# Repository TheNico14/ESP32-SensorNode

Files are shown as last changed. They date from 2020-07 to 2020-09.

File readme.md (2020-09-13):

# ESP32 SensorNode

ESP32 SensorNode is an ESP32 based multi-purpose sensor for use in home automation systems.
It connects via Wi-Fi to your home automation system and allows you to receive the measured parameters such as temperature, humidity, brightness, and movement.

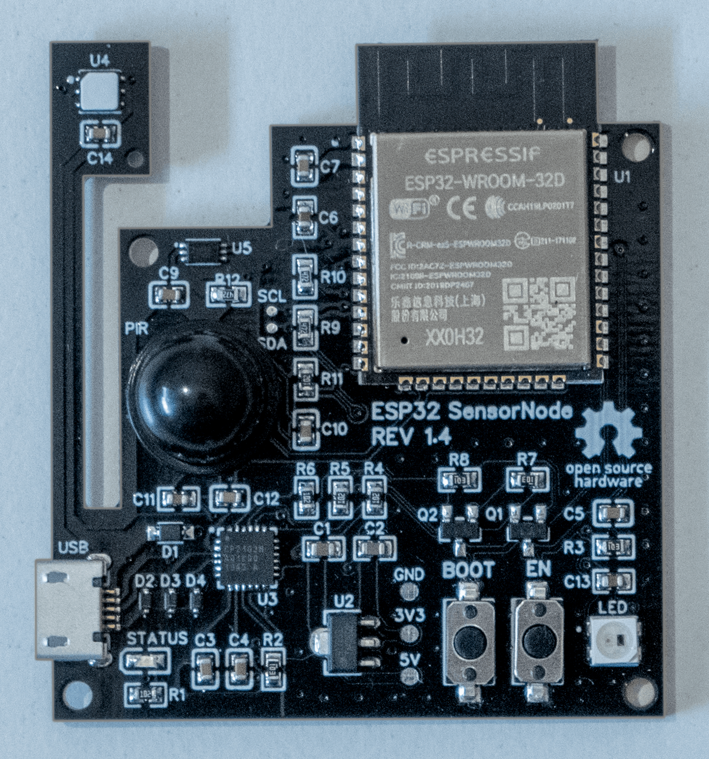
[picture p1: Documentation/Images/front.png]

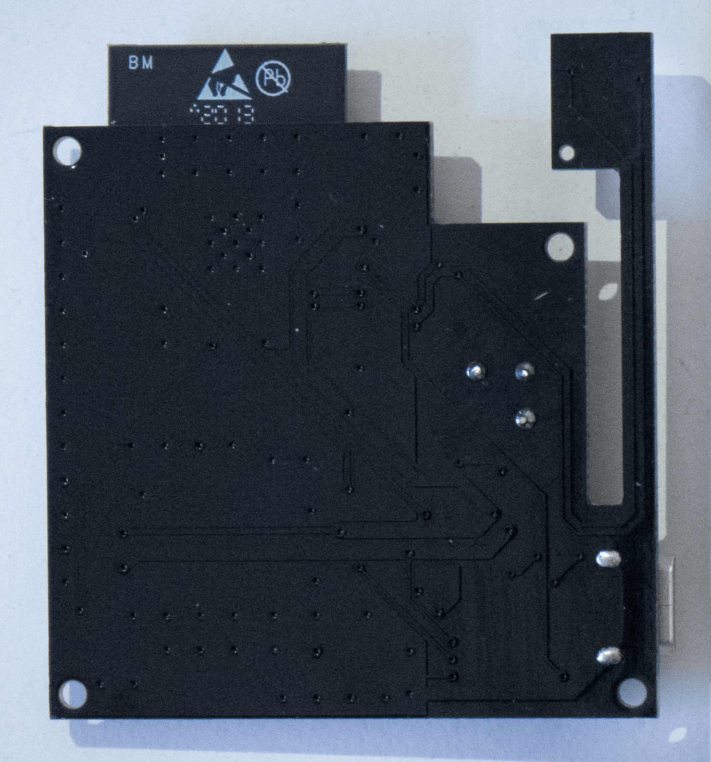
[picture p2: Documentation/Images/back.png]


The board can be programmed over USB and it's compatible with both [ESPHome](https://esphome.io/) (please read [below](https://github.com/TheNico14/ESP32-SensorNode#temperature-accuracy)) and the custom [ESP-IDF](https://github.com/espressif/esp-idf) software for use with [Home Assistant](https://www.home-assistant.io/). The custom ESP-IDF software utilizes [MQTT](https://en.wikipedia.org/wiki/MQTT) and it  should be compatible with other home automation systems.

The board dimensions are 5.08 x 4.57 cm (2 x 1.8 inches).

## Sensors

* Temperature / Humidity: SI7021\
    ± 0.4 °C (max), –10 to 85 °C\
    ± 3% RH (max), 0 – 80% RH
* Ambient Light: BH1750\
    1 - 65535 lx
* Motion sensor: AS312

## Features

* Programmable via USB
* Green status LED and digital RGB LED (WS2812B)
* Boot and Reset buttons

## Temperature accuracy

Due to the high consumption of the ESP32 with Wi-Fi enabled, the board tends to heat up over time and the measured temperature can increase by about 1°C.

The sensor has been isolated as much as possible from the rest of the system but it would be preferable to implement software that can limit consumption in order to obtain precise measurements.

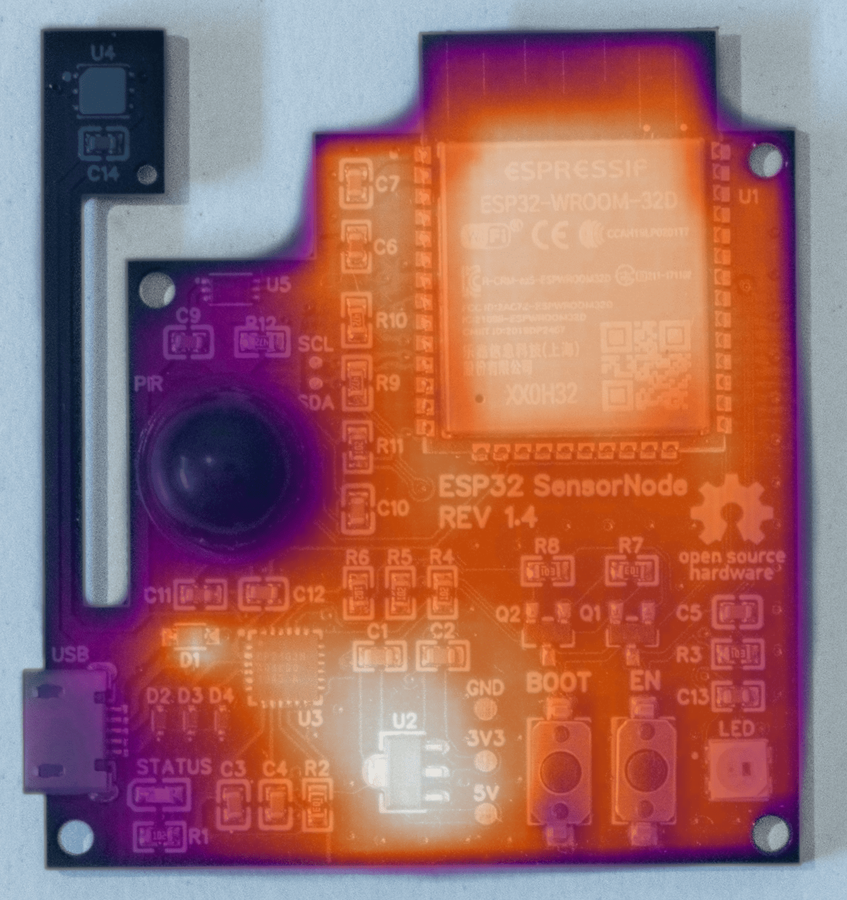
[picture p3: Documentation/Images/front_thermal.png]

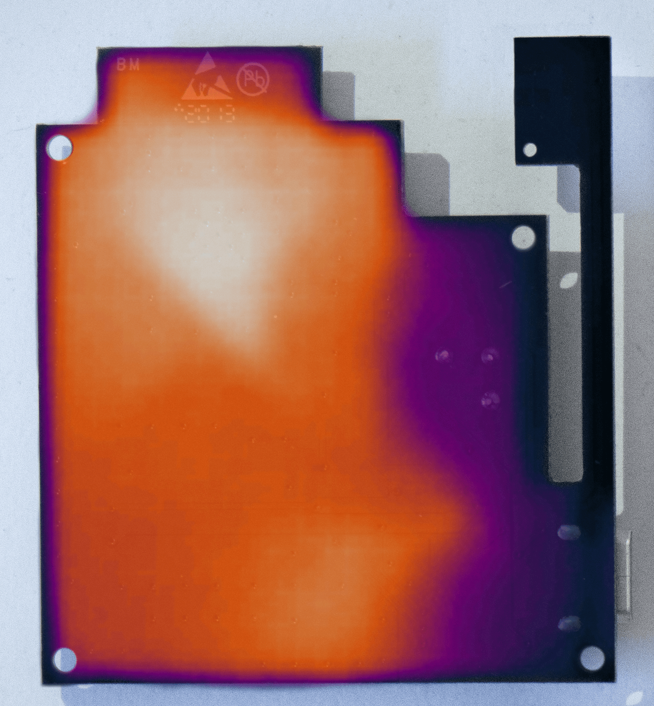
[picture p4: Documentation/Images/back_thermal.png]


At the time of writing, ESPHome allows you to configure wifi power saving but does not yet support light sleep, which would further reduce consumption and consequently unnecessary heat. It should be possible to use deep sleep with ESPHome but it has not been extensively tested.

An alternative custom software based on ESP-IDF has been developed for this board to minimize the problems caused by the high power consumption of the ESP32 microcontroller and its influence on measurements.
This software uses deep sleep and parsimonious use of Wi-Fi to minimize power consumption and the resulting increase of the board's temperature.

## Installation

The software installation guide can be found in the [project wiki](https://github.com/TheNico14/ESP32-SensorNode/wiki).

## Purchase an assembled unit

Since the production of this board requires relatively advanced soldering techniques and tools, upon request of some interested people, I opened a shop in Tindie where I sell already assembled boards.

[Purchase an ESP32 SensorNode on Tindie](https://www.tindie.com/products/thenico/esp32-sensornode/).

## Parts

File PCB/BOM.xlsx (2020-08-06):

Item | Label | Manufacturer Part | Value | Qty
1 | C1,C2,C6 | CL10A226MQ8NRNC | 22uF | 3
2 | C11,C13 | CL10A475KQ8NNND | 4.7uF | 2
3 | C3,C4,C5,C7,C9,C10,C12,C14 | 0603B104K500CT | 100nF | 8
4 | D1 | BAT760-7 |  | 1
5 | D2,D3,D4 | LESD5D5.0CT1G |  | 3
6 | EN,BOOT | K2-1107SP-A3SW-01 |  | 2
7 | LED | WS2812B-3535 |  | 1
8 | PIR | AS312 |  | 1
9 | Q1,Q2 | SS8050-G |  | 2
10 | R1,R4,R5,R6,R11 | 0603WAJ0102T5E | 1K | 5
11 | R2,R3,R7,R8 | 0603WAF1002T5E | 10K | 4
12 | R9,R10,R12 | WR06X472 JTL | 4.7K | 3
13 | STATUS | ORH-G36G |  | 1
14 | U1 | ESP32-WROOM-32D |  | 1
15 | U2 | HT7833 |  | 1
16 | U3 | CP2102N-A01-GQFN24 |  | 1
17 | U4 | SI7021 |  | 1
19 | U5 | BH1750FVI-TR |  | 1
20 | USB | U-F-M5WD-W-1 |  | 1
21 |  | PIR COVER |  | 1

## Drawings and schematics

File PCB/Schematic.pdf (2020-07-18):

## USB

## Power Supply

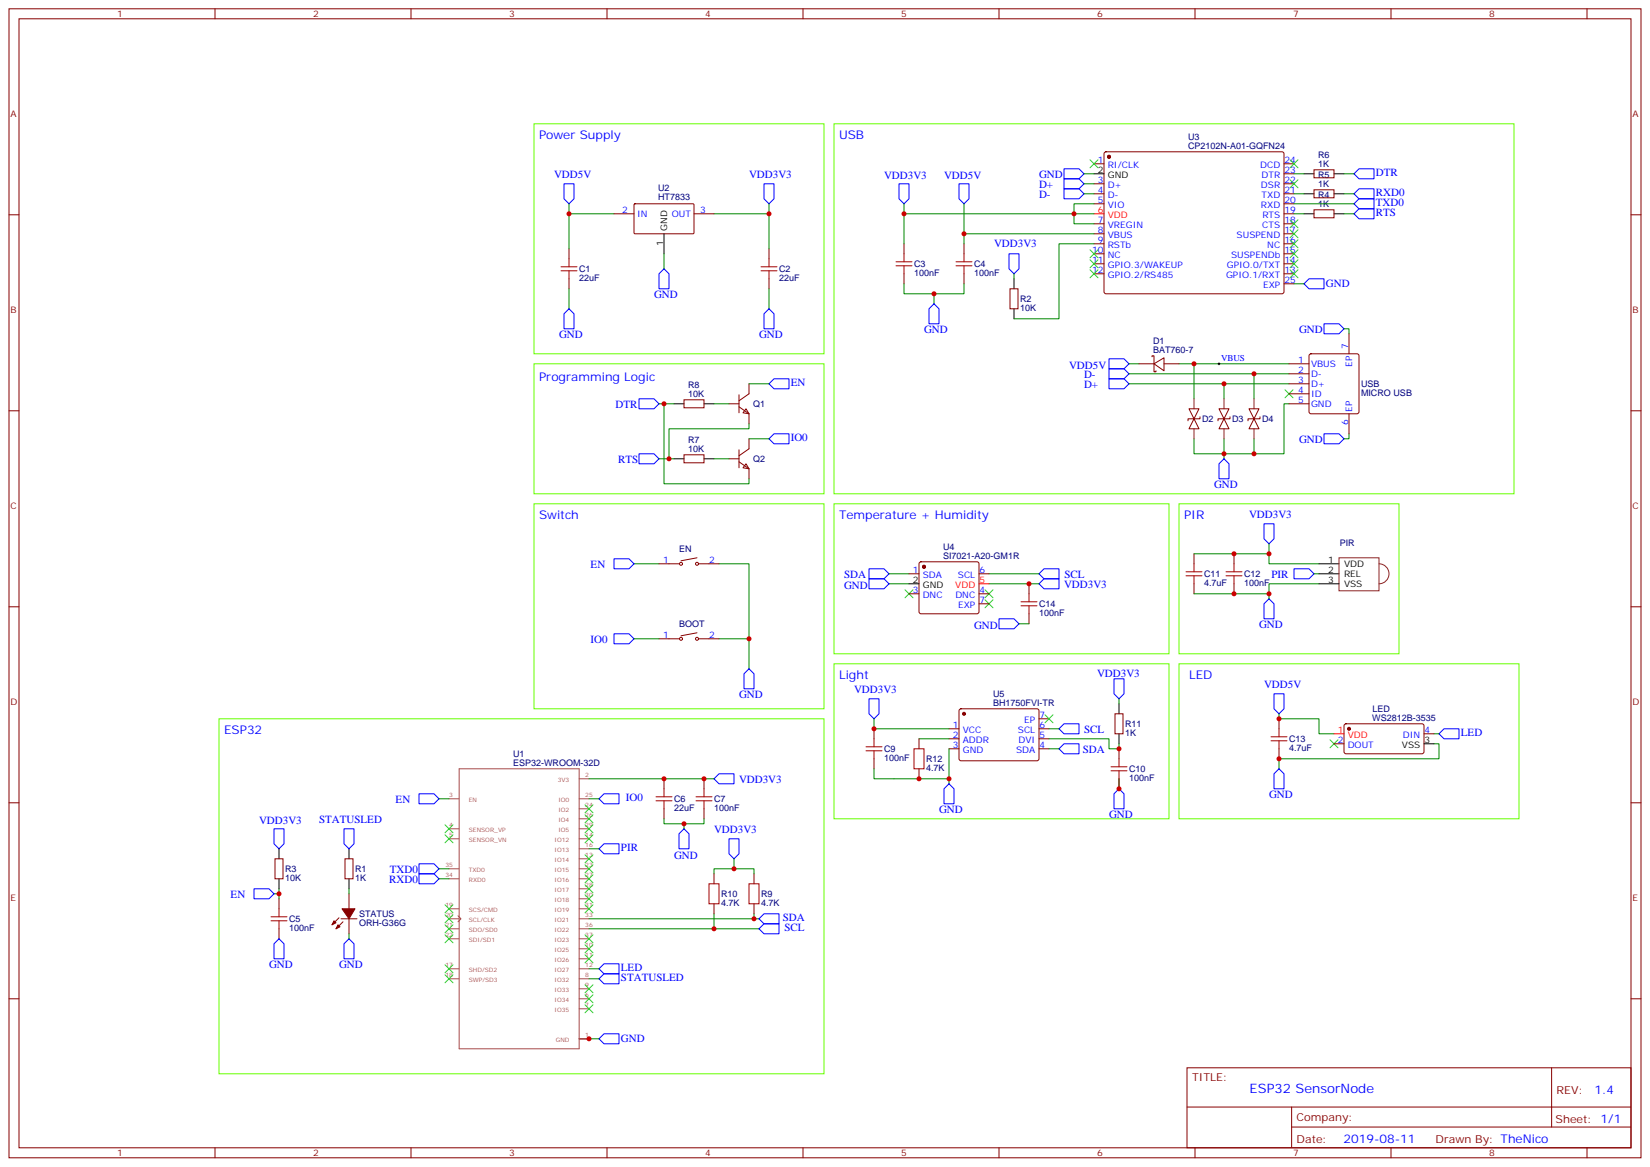
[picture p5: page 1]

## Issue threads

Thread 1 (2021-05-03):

PCB Project Files

hermannsblum, 2021-05-03:
Hi there, super nice project!
Would you be willing to share the design project files? I would be interested in modifying some things for my own needs, and that would make it much easier than copying over from the schematic.

crgarcia12, 2021-09-28:
+1!! Specially because some of those components are not that easy to get, so it would be very good to update it :)

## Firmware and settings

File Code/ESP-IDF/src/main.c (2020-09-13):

/**
 * @file     main.c
 * @author   Nicholas Polledri
 * @version  1.0
 * @date     13-09-2020
 * 
 * @brief    Main code of ESP32 SensorNode
 */

// Include libraries
#include <stdlib.h>
#include <stdint.h>
#include <esp_err.h>
#include <sys/time.h>
#include <esp_task_wdt.h>
#include <esp_sleep.h>
#include "freertos/FreeRTOS.h"
#include "freertos/event_groups.h"

#include "typedefs.h"
#include "configuration.h"

#include "gpio.h"
#include "i2c.h"
#include "bh1750.h"
#include "si7021.h"
#include "wifi.h"
#include "mqtt.h"

// Global variables
struct timeval timestamp;

// RTC variables
RTC_DATA_ATTR float rtc_temperature;
RTC_DATA_ATTR float rtc_humidity;
RTC_DATA_ATTR uint16_t rtc_light;
RTC_DATA_ATTR uint8_t rtc_pir;
RTC_DATA_ATTR uint8_t rtc_pir_pending;
RTC_DATA_ATTR struct timeval rtc_temperature_timestamp;
RTC_DATA_ATTR struct timeval rtc_humidity_timestamp;
RTC_DATA_ATTR struct timeval rtc_light_timestamp;
RTC_DATA_ATTR uint8_t rtc_temperature_valid;
RTC_DATA_ATTR uint8_t rtc_humidity_valid;
RTC_DATA_ATTR uint8_t rtc_light_valid;

// Private function declarations
esp_err_t setup(void);
esp_err_t check_measurements(void);
uint8_t handle_measurement(measurement_type type, void *measurement, uint8_t *rtc_measurement_valid, void *rtc_measurement, float update_threshold, struct timeval timestamp, struct timeval *rtc_timestamp);
void start_deep_sleep(void);

// Functions

/**
 * @brief    Main function
 * 
 */
void app_main(void)
{
    gettimeofday(&timestamp, NULL); // Get current timestamp

    esp_sleep_wakeup_cause_t wakeup_cause = esp_sleep_get_wakeup_cause();

    switch (wakeup_cause)
    {

    // Actions to execute after a routine wakeup
    case ESP_SLEEP_WAKEUP_TIMER:
        i2c_setup();
        check_measurements();
        break;

    // Actions to execute after a PIR interrupt wakeup
    case ESP_SLEEP_WAKEUP_EXT0:
        gpio_setup();
        handle_pir();
        break;

    // Actions to execute after every other wakeup cause
    default:
        setup();
        mqtt_send_autodiscovery();
        break;
    }

    if (rtc_pir_pending)
        handle_pir();

    start_deep_sleep();
}

/**
 * @brief    Sensors setup needed to initialize sensors after first boot
 * 
 * @return   esp_err_t status
 */
esp_err_t setup(void)
{
    rtc_light_valid = 0;
    rtc_temperature_valid = 0;
    rtc_humidity_valid = 0;

    ESP_ERROR_CHECK(i2c_setup());

    bh1750_mode_t bh1750_mode = BH1750_MODE;
    bh1750_resolution_t bh1750_resolution = BH1750_RESOLUTION;
    ESP_ERROR_CHECK(bh1750_setup(bh1750_mode, bh1750_resolution));

    si7021_resolution_t si7021_resolution = SI7021_RESOLUTION;
    ESP_ERROR_CHECK(si7021_setup(si7021_resolution));

    return ESP_OK;
}

/**
 * @brief    Sensor reading and measurements handler function.
 *           This function reads the value of the light, temperature and humidity
 *           measurements, then checks if the new measurements need to be sent
 *           and if so, requests the Wi-Fi connection to be established and sends
 *           the required measurements via MQTT.
 * 
 * @return   esp_err_t status
 */
esp_err_t check_measurements(void)
{
    uint8_t light_needs_update = 0,
            temperature_needs_update = 0,
            humidity_needs_update = 0;

    // BH1750 measurement
    uint16_t light;
    ESP_ERROR_CHECK(bh1750_read(&light)); // Sensor reading
    light_needs_update = handle_measurement(int_t,
                                            &light,
                                            &rtc_light_valid,
                                            &rtc_light,
                                            LIGHT_UPDATE_THRESHOLD,
                                            timestamp,
                                            &rtc_light_timestamp);

    // Si7021 measurement
    float temperature, humidity;
    ESP_ERROR_CHECK(si7021_measure(&temperature, &humidity)); // Sensor reading
    temperature_needs_update = handle_measurement(float_t,
                                                  &temperature,
                                                  &rtc_temperature_valid,
                                                  &rtc_temperature,
                                                  TEMPERATURE_UPDATE_THRESHOLD,
                                                  timestamp,
                                                  &rtc_temperature_timestamp);

    humidity_needs_update = handle_measurement(float_t,
                                               &humidity,
                                               &rtc_humidity_valid,
                                               &rtc_humidity,
                                               HUMIDITY_UPDATE_THRESHOLD,
                                               timestamp,
                                               &rtc_humidity_timestamp);

    // Check if an update is needed
    if (light_needs_update || temperature_needs_update || humidity_needs_update)
    {
        ESP_ERROR_CHECK(wifi_setup());     // Turn on Wi-Fi
        esp_err_t ret = wifi_event_wait(); // Wait for Wi-Fi connection

        if (ret == ESP_OK) // If Wi-Fi connection is established
        {
            ESP_ERROR_CHECK(mqtt_setup()); // Setup MQTT

            // Light update check
            if (light_needs_update)
            {
                ESP_ERROR_CHECK_WITHOUT_ABORT(mqtt_send_light(light)); // Send light value
                if (mqtt_event_wait() != ESP_OK)                       // Wait for MQTT ack
                    ret = ESP_FAIL;
            }

            // Temperature update check
            if (temperature_needs_update)
            {
                ESP_ERROR_CHECK_WITHOUT_ABORT(mqtt_send_temperature(temperature)); // Send temperature value
                if (mqtt_event_wait() != ESP_OK)                                   // Wait for MQTT ack
                    ret = ESP_FAIL;
            }

            // Humidity update check
            if (humidity_needs_update)
            {
                ESP_ERROR_CHECK_WITHOUT_ABORT(mqtt_send_humidity(humidity)); // Send humidity value
                if (mqtt_event_wait() != ESP_OK)                             // Wait for MQTT ack
                    ret = ESP_FAIL;
            }
        }
        return ret;
    }
    return ESP_OK;
}

/**
 * @brief    Checks if new measurement needs to be sent.
 * 
 * @param    type: int_t or float_t 
 * @param    measurement: pointer to new measurement
 * @param    rtc_measurement_valid: pointer to valid rtc measurement flag
 * @param    rtc_measurement: pointer to rtc measurement
 * @param    update_threshold: threshold to cross for sending a measurement
 * @param    timestamp: actual timestamp
 * @param    rtc_timestamp: pointer to rtc measurement timestamp
 * @return   uint8_t: 0-1 needs update, -1 error
 */
uint8_t handle_measurement(measurement_type type, void *measurement, uint8_t *rtc_measurement_valid, void *rtc_measurement, float update_threshold, struct timeval timestamp, struct timeval *rtc_timestamp)
{
    float delta, value, rtc_value;

    if (type == int_t) // If measurement type is integer
    {
        value = *((int16_t *)measurement); // Cast values with integer type
        rtc_value = *((int16_t *)rtc_measurement);
    }
    else if (type == float_t) // If measurement type is float
    {
        value = *((float *)measurement); // Cast values with float type
        rtc_value = *((float *)rtc_measurement);
    }
    else           // If measurement type is not correct
        return -1; // Return error value

    if (*rtc_measurement_valid == 1) // If RTC measurement is valid
    {
        delta = abs(value - rtc_value);

        if (delta > update_threshold || (timestamp.tv_sec - rtc_timestamp->tv_sec) >= SENSOR_UPDATE_INTERVAL_MAX) // If delta is bigger than thresold or last value is expired
        {
            if (type == int_t)
                *((int16_t *)rtc_measurement) = *((int16_t *)measurement); // Save measurement as integer
            else if (type == float_t)
                *((float *)rtc_measurement) = *((float *)measurement); // Save measurement as float

            *rtc_measurement_valid = 1;
            *rtc_timestamp = timestamp;
            return 1;
        }
        return 0;
    }
    else // If RTC measurement is not valid
    {
        if (type == int_t)
            *((int16_t *)rtc_measurement) = *((int16_t *)measurement); // Save measurement as integer
        else if (type == float_t)
            *((float *)rtc_measurement) = *((float *)measurement); // Save measurement as float

        *rtc_measurement_valid = 1;

        return 1;
    }
}

/**
 * @brief    Deep sleep preparation and activation
 * 
 */
void start_deep_sleep(void)
{
    esp_sleep_enable_timer_wakeup(SLEEP_INTERVAL_SEC * 1000000);  // Enable wakeup after time interval
    esp_sleep_enable_ext0_wakeup((gpio_num_t)PIR_GPIO, !rtc_pir); // Enable wakeup after PIR interrupt

    fflush(stdout); // Empty the stdout stream

    esp_deep_sleep_start(); // Start deep sleep
}

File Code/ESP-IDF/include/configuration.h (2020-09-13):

/**
 * @file     configuration.h
 * @author   Nicholas Polledri
 * @version  1.0
 * @date     13-09-2020
 * 
 * @brief    Configuration file for ESP32 SensorNode
 */

#ifndef CONFIGURATION_H
#define CONFIGURATION_H

// GENERAL
#define SLEEP_INTERVAL_SEC 5             // Time between measurements [sec]
#define SENSOR_UPDATE_INTERVAL_MAX 300   // Force an update after determined time [sec]
#define LIGHT_UPDATE_THRESHOLD 2         // Update if light changes more than this [lux]
#define TEMPERATURE_UPDATE_THRESHOLD 0.2 // Update if temperature changes more than this [°C/°F]
#define HUMIDITY_UPDATE_THRESHOLD 2      // Update if humidity changes more than this [%]

#define TEMPERATURE_USE_FAHRENHEIT 0 // Enable Fahrenheit measurements

// WI-FI
#define WIFI_SSID "wifi"
#define WIFI_PASSWORD "password"
#define WIFI_MAXIMUM_RETRY 5

#define WIFI_STATIC_IP 0 // Enable static IP
#define WIFI_IP_ADDRESS "192.168.1.100"
#define WIFI_DEFAULT_GATEWAY "192.168.1.1"
#define WIFI_NETMASK "255.255.255.0"

// MQTT
#define MQTT_BROKER "mqtt://192.168.1.10" // Broker IP (mqtt://X.X.X.X)
#define MQTT_USERNAME "user"              // MQTT username
#define MQTT_PASSWORD "password"          // MQTT password
#define MQTT_PORT 1883                    // MQTT port

#define MQTT_NODE_NAME "ESP32-SensorNode" // ESP32 SensorNode name on MQTT
#define MQTT_ENABLE_DISCOVERY 1           // Enable automatic Home Assistant sensor discovery

#define MQTT_LIGHT_TOPIC "light"             // Light topic
#define MQTT_TEMPERATURE_TOPIC "temperature" // Temperature topic
#define MQTT_HUMIDITY_TOPIC "humidity"       // Humidity topic
#define MQTT_PIR_TOPIC "motion"              // Motion topic

/* ADVANCED CONFIGURATION - From here don't edit if not sure ******************/

// MQTT
#define MQTT_SENSOR_DISCOVERY_TOPIC "homeassistant/sensor"
#define MQTT_BINARY_SENSOR_DISCOVERY_TOPIC "homeassistant/binary_sensor"
#define MQTT_TOPIC_MAX_LEN 80
#define MQTT_CONFIGURATION_PAYLOAD_MAX_LEN 200
#define MQTT_MEASUREMENT_MAX_LEN 10

// TIMEOUTS
#define WIFI_SETUP_TIMEOUT_MS 500 // Wi-Fi connection timeout
#define MQTT_SEND_TIMEOUT_MS 200  // MQTT message timeout

// EVENT BITS
#define WIFI_CONNECTED_BIT BIT0
#define WIFI_FAIL_BIT BIT1
#define MQTT_PUBLISHED_BIT BIT2
#define MQTT_ERROR_BIT BIT3

// I2C
#define I2C_MASTER_SCL_IO 22      // I2C clock pin
#define I2C_MASTER_SDA_IO 21      // I2C data pin
#define I2C_MASTER_NUM 0          // I2C port
#define I2C_MASTER_FREQ_HZ 400000 // I2C bus frequency

// BH1750 - Light sensor
#define BH1750_ADDR 0x23                   // Sensor address
#define BH1750_MODE BH1750_MODE_CONTINIOUS // Sensor mode
#define BH1750_RESOLUTION BH1750_RES_HIGH  // Sensor resolution

#define BH1750_OPCODE_HIGH 0x0 // I2C Operation Codes
#define BH1750_OPCODE_HIGH2 0x1
#define BH1750_OPCODE_LOW 0x3
#define BH1750_OPCODE_CONT 0x10
#define BH1750_OPCODE_OT 0x20
#define BH1750_OPCODE_POWER_DOWN 0x00
#define BH1750_OPCODE_POWER_ON 0x01
#define BH1750_OPCODE_MT_HI 0x40
#define BH1750_OPCODE_MT_LO 0x60

// SI7021 - Temperature and humidity sensor
#define SI7021_ADDR 0x40                   // Temperature and humidity sensor I2C address
#define SI7021_RESOLUTION SI7021_RES_HIGH2 // Temperature and humidity sensor resolution

#define SI7021_COMMAND_READ_RH 0xF5 // I2C Operation Codes
#define SI7021_COMMAND_READ_TEMP 0xF3
#define SI7021_COMMAND_READ_TEMP_AFTER_RH 0xE0
#define SI7021_REG_WRITE 0xE6
#define SI7021_REG_READ 0xE7
#define SI7021_RESET 0xFE

#define MEASUREMENT_WAIT 25 // Measurement delay

// AS312 - PIR
#define PIR_GPIO 13 // PIR GPIO

#endif

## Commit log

2020-07-18 Updated readme and C6 value
    [BOM.xlsx, Pick_and_place.csv]
2020-08-06 Documentation update
    [BOM.xlsx]
2020-09-13 ESP-IDF software update
    [configuration.h]
